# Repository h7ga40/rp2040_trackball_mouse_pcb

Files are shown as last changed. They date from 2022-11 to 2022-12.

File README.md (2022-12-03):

# PCB for Kensington trackball with RP2040

[Kensington Orbit Trackball with Scroll Ring](https://www.kensington.com/p/products/electronic-control-solutions/trackball-products/orbit-trackball-with-scroll-ring/)の基板を[PGA2040](https://shop.pimoroni.com/products/pga2040)を使っ基板に置き換えるためのKiCadプロジェクト

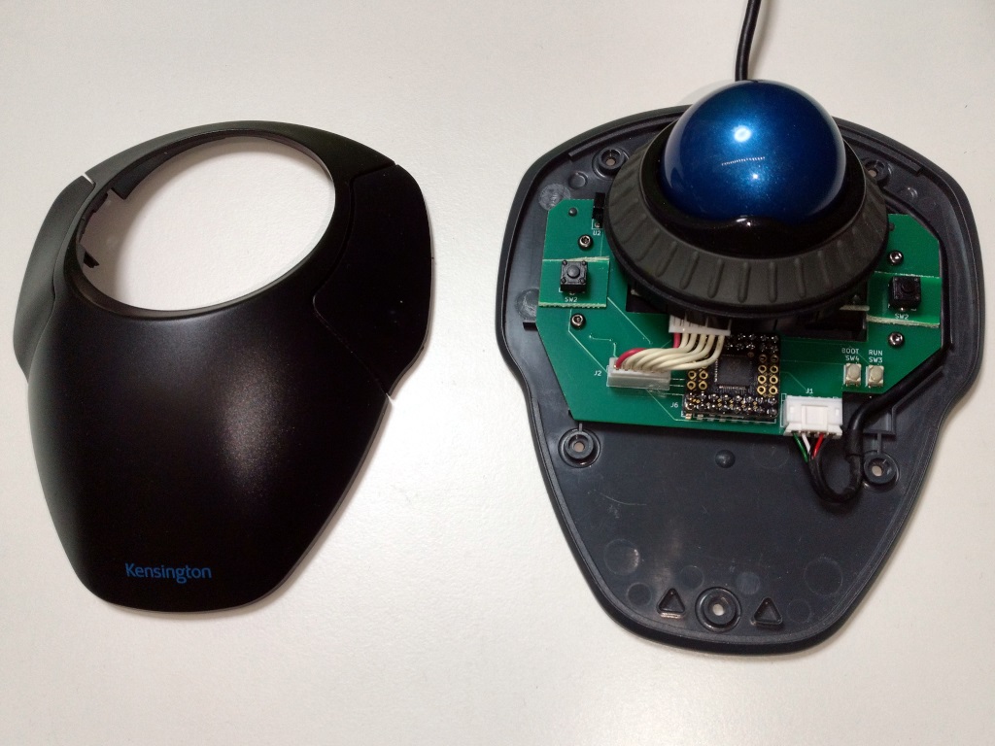
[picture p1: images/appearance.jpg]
Trackball


## 基板発注時の注意

板厚は**1.2mm**です。

## 主要部品

|部品|入手先|備考|
|-|-|-|
|PGA2040|<https://akizukidenshi.com/catalog/g/gM-16762/>|Raspberry pi picoと同じCPU|
|IR928-6C-F|<https://www.marutsu.co.jp/pc/i/12907560/>|ホイール用２相エンコーダのLED</br>見た目が同じなので選択|
|PT5529B/L2/H3|<https://www.marutsu.co.jp/pc/i/13719542/>|ホイール用２相エンコーダのフォトトランジスタ</br>見た目が同じなので選択|
|LMV393D|<https://www.marutsu.co.jp/pc/i/30637519/>|２相エンコーダ信号用のコンパレータ|
|B6B-PH-K-S|<https://www.marutsu.co.jp/pc/i/46628/>|ADNS-5050との接続用コネクタ|
|S5B-PH-K-S|<https://www.marutsu.co.jp/pc/i/54957/>|USBケーブルとの接続用コネクタ|
|kailh mute switch|<https://www.amazon.co.jp/s?k=kailh+mute+switch>|マウスボタン</br>[秋月のタクトスイッチ](https://akizukidenshi.com/catalog/g/gP-14892/)で代用（1.6mm(7.3mm-5.7mm)の底上げが必要）|
|タクトスイッチ|<https://akizukidenshi.com/catalog/g/gP-06184/>|RP2040のリセットとモード選択用|

## ソフトウェア

[こちら](https://github.com/h7ga40/rp2040_trackball_mouse)にソフトウェアがあります。

## 部品実装

PGA2040周辺はこのような感じ

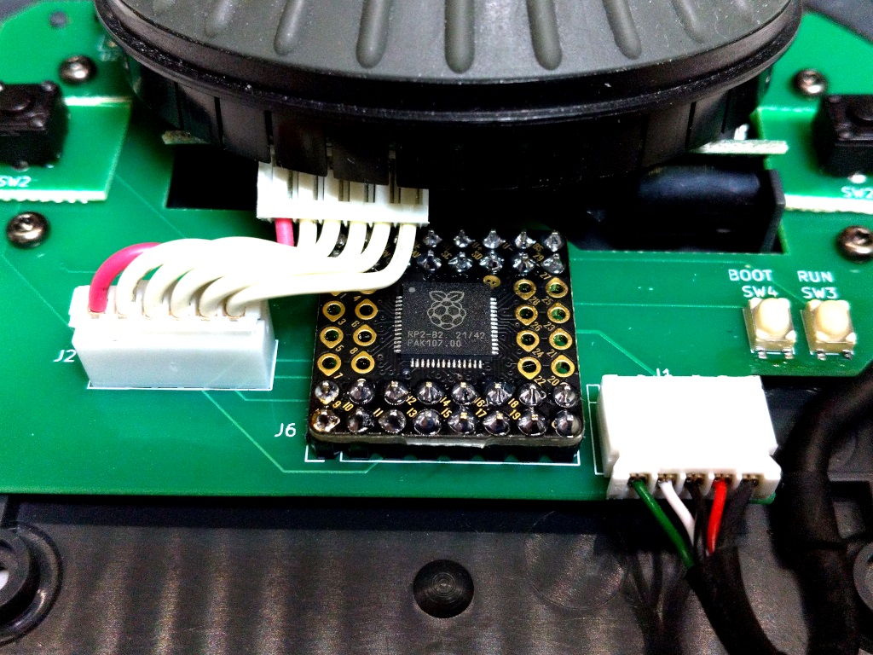
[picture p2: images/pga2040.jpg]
PGA2040周辺


## その他の情報

[コネクテッド・マウス](https://www.slideshare.net/HiroakiNagashima1/ss-250643168)

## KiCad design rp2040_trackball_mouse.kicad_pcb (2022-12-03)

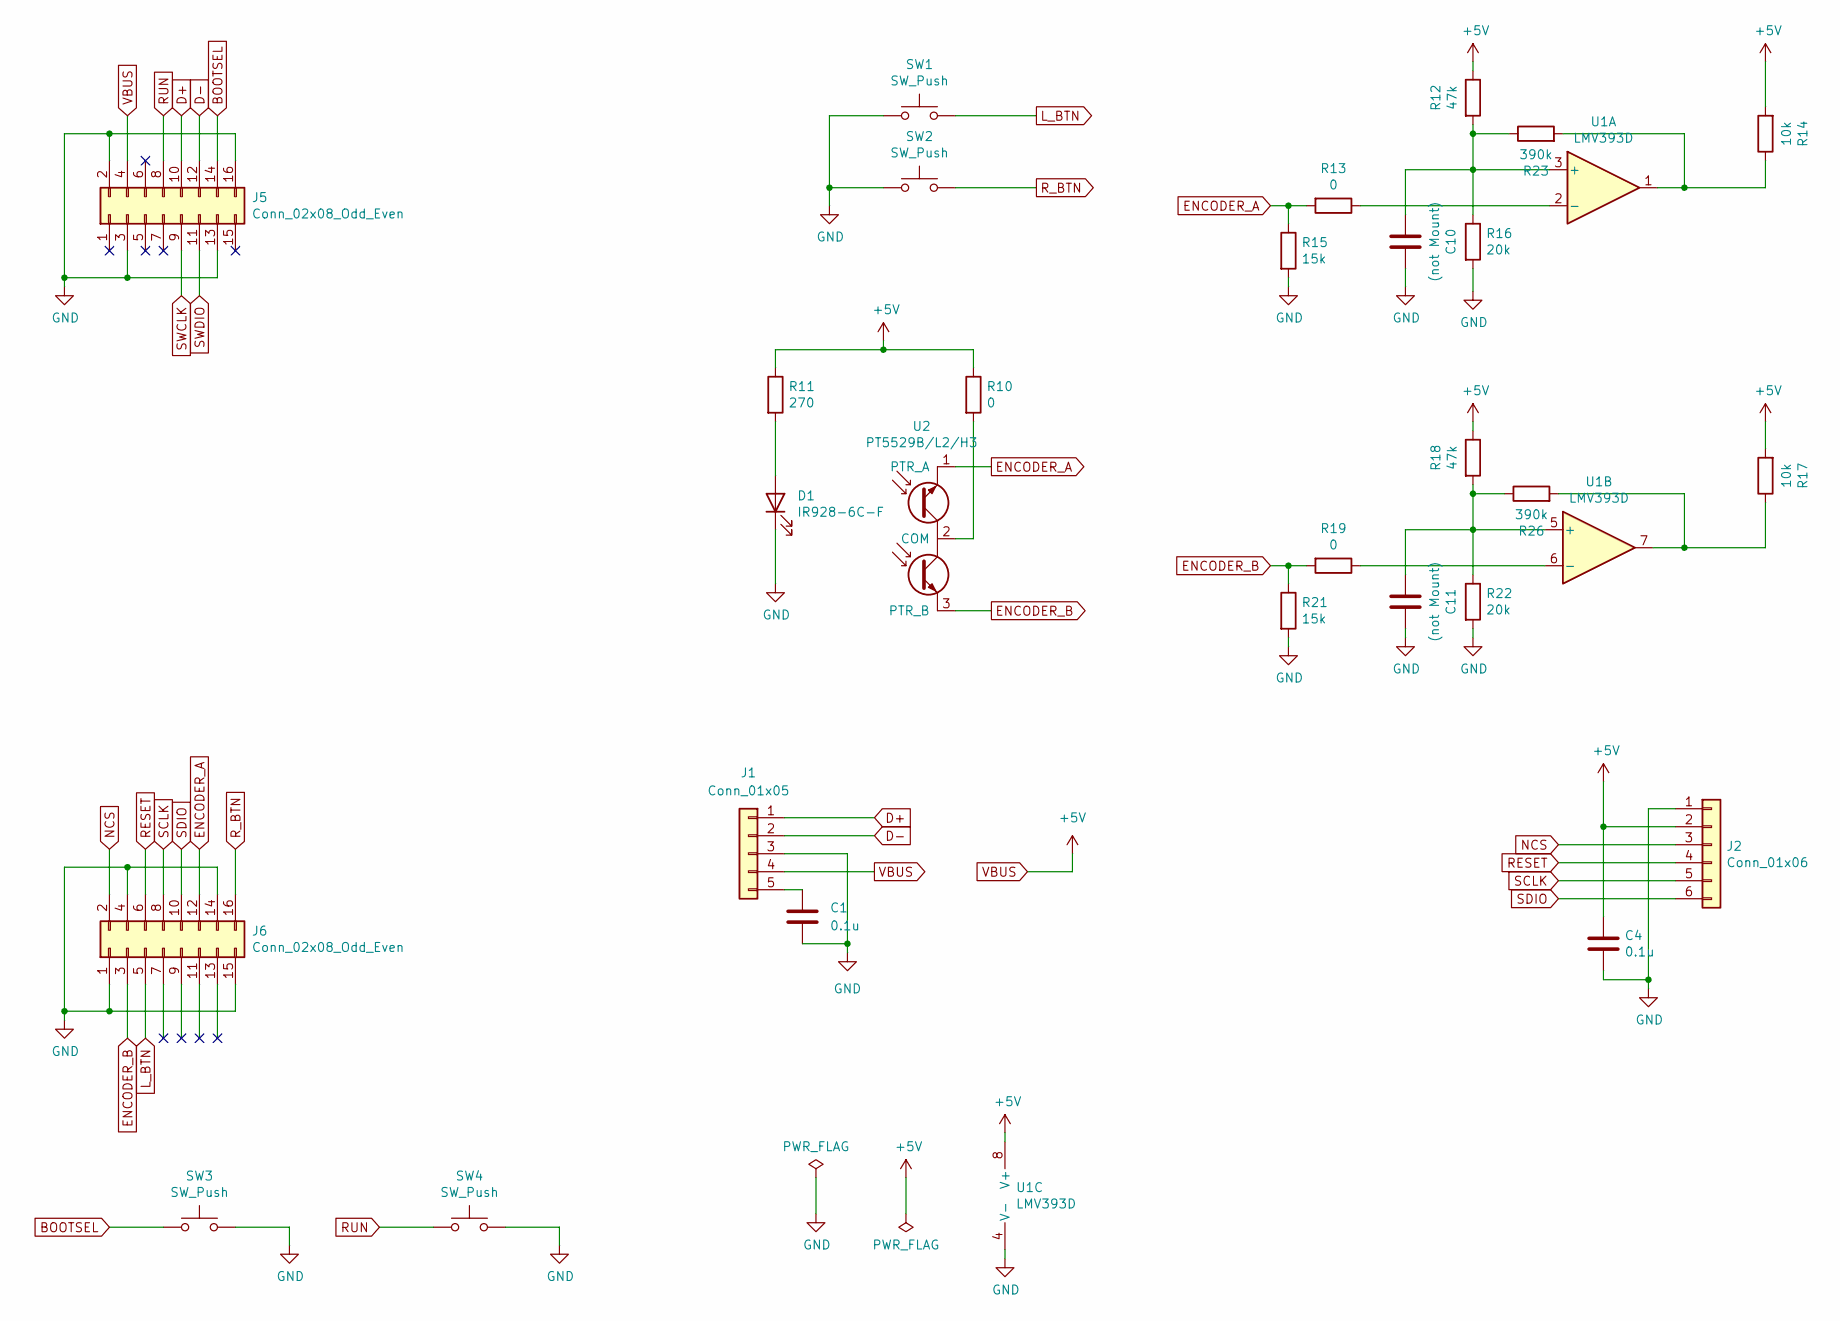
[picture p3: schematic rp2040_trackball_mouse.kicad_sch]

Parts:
C1, C4: 0.1u; C_0603_1608Metric_Pad1.08x0.95mm_HandSolder
C10, C11: (not Mount); C_0603_1608Metric_Pad1.08x0.95mm_HandSolder
D1: IR928-6C-F; LED_D2.0mm_W4.8mm_H2.5mm_FlatTop
J1: Conn_01x05; JST_PH_S5B-PH-K_1x05_P2.00mm_Horizontal
J2: Conn_01x06; JST_PH_B6B-PH-K_1x06_P2.00mm_Vertical
J5, J6: Conn_02x08_Odd_Even; PinHeader_2x08_P2.54mm_Vertical
R10, R13, R19: 0; R_0603_1608Metric_Pad0.98x0.95mm_HandSolder
R11: 270; R_0603_1608Metric_Pad0.98x0.95mm_HandSolder
R12, R18: 47k; R_0603_1608Metric_Pad0.98x0.95mm_HandSolder
R14, R17: 10k; R_0603_1608Metric_Pad0.98x0.95mm_HandSolder
R15, R21: 15k; R_0603_1608Metric_Pad0.98x0.95mm_HandSolder
R16, R22: 20k; R_0603_1608Metric_Pad0.98x0.95mm_HandSolder
R23, R26: 390k; R_0603_1608Metric_Pad0.98x0.95mm_HandSolder
SW1, SW2: SW_Push; CMI6273
SW3, SW4: SW_Push; SW_SPST_PTS810
U1: LMV393D; SOP-8_3.9x4.9mm_P1.27mm
U2: PT5529B/L2/H3; PinHeader_1x03_P2.54mm_Vertical

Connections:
BOOTSEL: J5.14, SW3.1
D+: J1.1, J5.10
D-: J1.2, J5.12
ENCODER_A: J6.12, R13.2, R15.1, U2.1 (PTR_A)
ENCODER_B: J6.3, R19.2, R21.1, U2.3 (PTR_B)
GND: C1.2, C4.2, C10.1, C11.2, D1.1 (K), J1.3, J2.1, J5.2, J5.3, J5.13, J5.16, J6.1, J6.4, J6.14, J6.15, R15.2, R16.2, R21.2, R22.2, SW1.1, SW2.1, SW3.2, SW4.2, U1.4 (V-)
L_BTN: J6.5, SW1.2
NCS: J2.3, J6.2
unnamed: C1.1, J1.5
unnamed: C10.2, R12.2, R16.1, R23.1, U1.3 (+)
unnamed: C11.1, R18.2, R22.1, R26.1, U1.5 (+)
unnamed: D1.2 (A), R11.2
unnamed: R10.2, U2.2 (COM)
unnamed: R13.1, U1.2 (-)
unnamed: R14.1, R23.2, U1.1
unnamed: R17.1, R26.2, U1.7
unnamed: R19.1, U1.6 (-)
RESET: J2.4, J6.6
RUN: J5.8, SW4.1
R_BTN: J6.16, SW2.2
SCLK: J2.5, J6.8
SDIO: J2.6, J6.10
SWCLK: J5.9
SWDIO: J5.11
VBUS: C4.1, J1.4, J2.2, J5.4, R10.1, R11.1, R12.1, R14.2, R17.2, R18.1, U1.8 (V+)

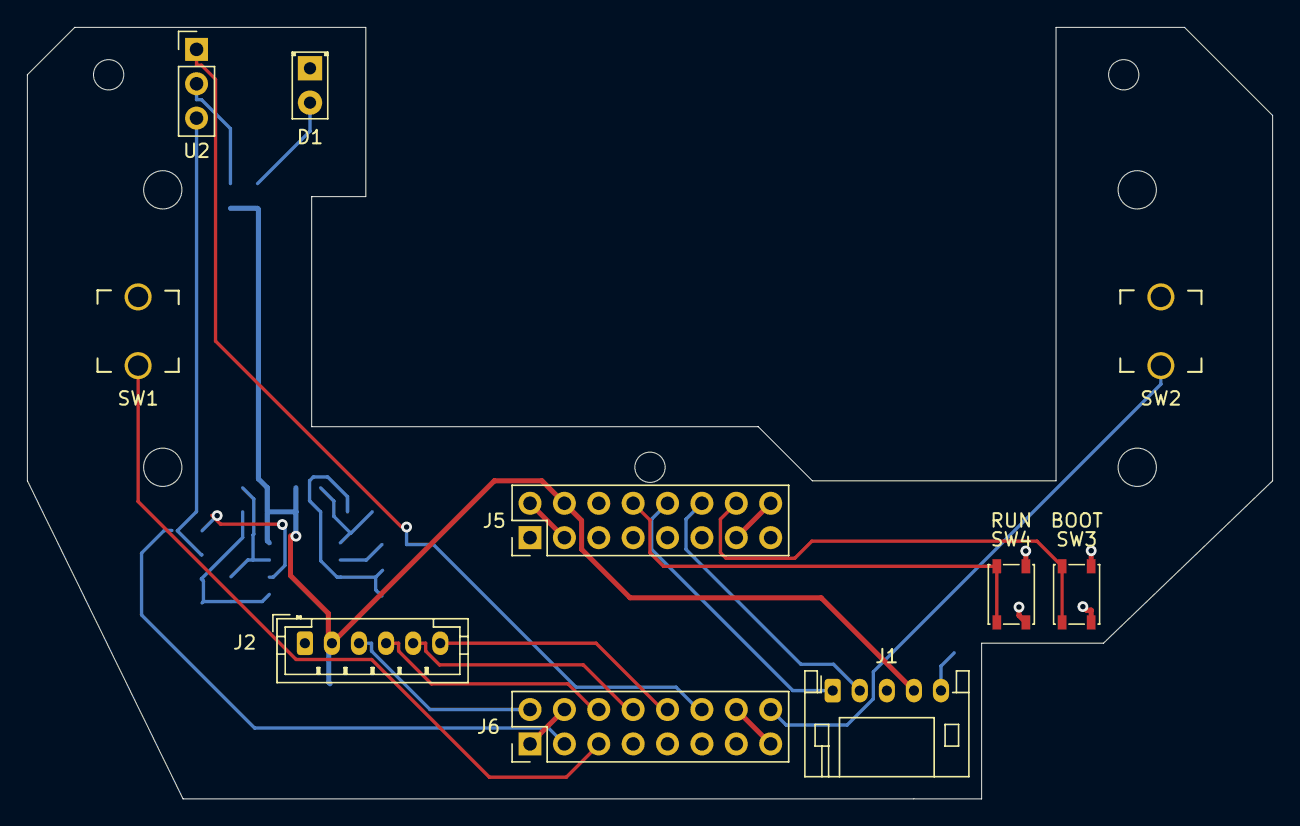
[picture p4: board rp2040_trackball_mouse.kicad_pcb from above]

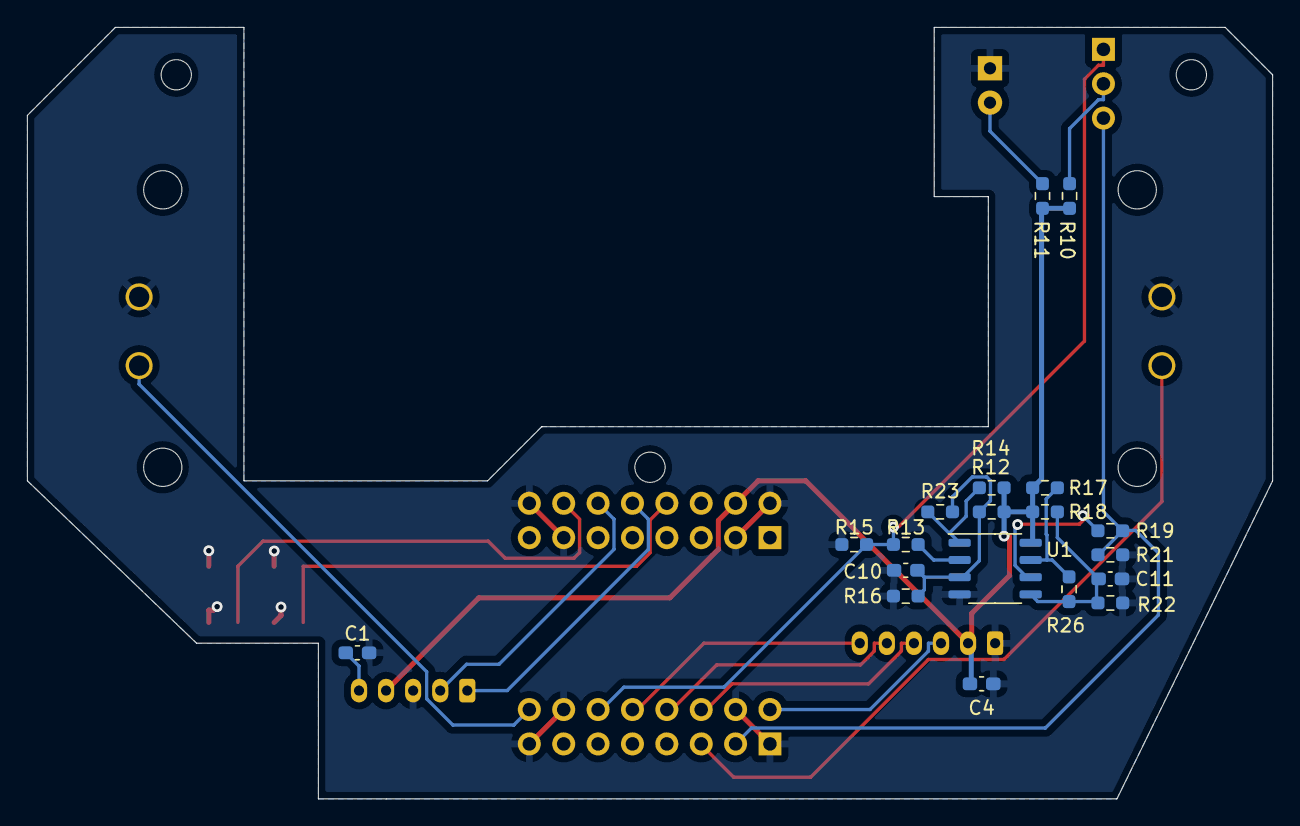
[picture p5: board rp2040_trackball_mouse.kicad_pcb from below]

Board: 2 copper layers, 92.0 x 57.0 mm, 29 parts (19 on the bottom side), 23 nets.

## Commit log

2022-11-23 ファイルを登録
    [rp2040_trackball_mouse.kicad_pcb, rp2040_trackball_mouse.kicad_sch]
2022-11-23 kicad_prlファイルを削除
2022-11-27 READMEを更新
2022-11-27 誤字を修正
2022-11-30 回路図を更新
    [rp2040_trackball_mouse.kicad_pcb, rp2040_trackball_mouse.kicad_sch]
2022-12-03 ホイールがぎこちないのを記述
    [rp2040_trackball_mouse.kicad_pcb, rp2040_trackball_mouse.kicad_sch]
2022-12-03 仮に入れていた値を削除
    [rp2040_trackball_mouse.kicad_pcb, rp2040_trackball_mouse.kicad_sch]
2022-12-03 ホイールの動作はGPIOをプルダウンして安定化したので記述削除
